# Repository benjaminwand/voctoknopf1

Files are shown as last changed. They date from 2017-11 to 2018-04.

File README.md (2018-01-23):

This is a hardware-interface vor [voctomix](https://github.com/voc/voctomix/tree/master/voctocore), developed late 2017 and tried in a few talks at 34c3.

### Key features are:

* Custom PCB
* Cherry MX switches with custom 3D-printed keycaps
* 3D-printed top and bottom enclosure parts “sandwiched” around the PCB
* Arduino Nano which sends commands to a computer via USB
* Computer relays the commands to the voctomix software via [socat](https://linux.die.net/man/1/socat)
* is supposed to learn to speak TPC on its own (was not implemented on 34c3)

This is a community project with help from many friends.

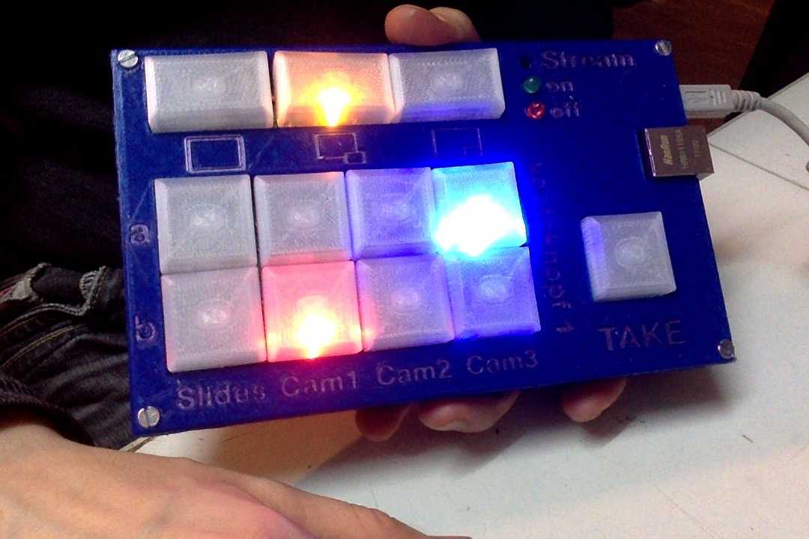
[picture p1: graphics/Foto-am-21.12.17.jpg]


The **keycaps** are [gothic.FCStd](https://github.com/benjaminwand/Cherry-MX-keycaps/tree/master/with%20LED), 20 * 33,5 mm for the composite mode buttons and 25 * 25 mm for the camera/channel buttons and the take button. Please adjust the side lengths in the spreadsheet of the file, but there are also stl files in the ‘case’ folder.

### Lessons learnt after PCB production V 1.0: 
* slightly wrong footprint for resistors, too short
* wrong footprint for cherry switches, contacts for LEDs are too far apart
* the Cherry MX I got from reichelt.de aren’t for PCB mount, be more careful when shopping
* wrong footprint for StreamOn switch, fix: bend up two diagonal contacts
* 1.5k ohm pull-up-resistors are required between A4 and 5V and A5 and 5V
* the buttons would look more evenly illuminated if the LED was behind the switches -> turn the Cherry MX around 180°

See [here](graphics/bugfixes.jpg) for a photo with hardware fixes.
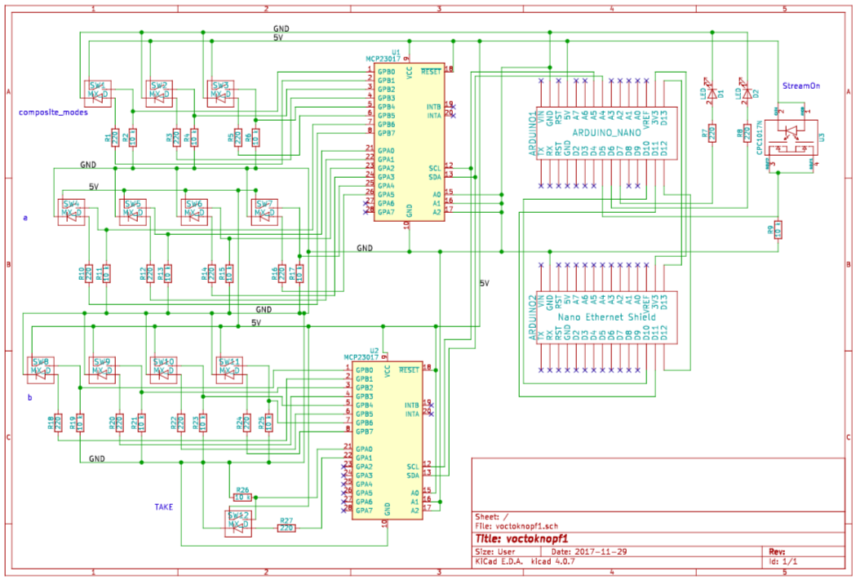
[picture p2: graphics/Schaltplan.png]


### Lessons learnt regarding the case
* I’ve actually included small changes into the file after printing, print as-is, and slice everything the way around it is supposed to end up. Yes, printing the buttons upside down would be faster but looks ugly. I found it easier to remove the support-material when the buttons were printed with raft.
* Print everything with transparent filament and then paint up the upper side of the case (except from the letters !!!) with a dark-ish pen that isn’t water-soluble. Due to the LEDs inside, the letters become illuminated.

### Shopping list
* 1 arduino nano (clone)
* 1 ethernet-shield for arduino nano
* 12 Cherry MX switches with holes for LEDs, for PCB mount. I used ‘clear’ and would go for ‘brown’ next time.
* 12 3mm LEDs, 4 red, 4 blue, 4 other color (yellow). alternatively there are probably special LEDs für Cherry MX but I didn’t have the time for searching
* 1 tact switch for StreamOn-button 
* 1 5mm LED red
* 1 5mm LED green
* 14 resistors 220
* 13 resistors 10k
* 2 resistors 1.5k
* 4 nuts and bolts M3 (best: screws with countersunk head)

### Status
One device has been built so far and has been successfully used in a few talks on the 34th Chaos Communication Congress.

### References
* [Cherry MX keycaps](https://github.com/benjaminwand/Cherry-MX-keycaps)
* [Geekend Prototype](https://github.com/benjaminwand/voctoknopf-Geekend-prototype)
* [Voctoknopf as a handheld controller](https://github.com/benjaminwand/voctoplay)

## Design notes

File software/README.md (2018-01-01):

# Software for voctoknopf1

The software is written in C using the Arduino framework.  
The source code can be found in [./voctoknopf1/](./voctoknopf1).

## Compiling and flashing

In order to compile the source code you can either use the Arduino IDE or <http://platformio.org>.  

### platformio

The following commands have to be executed in the `software/` folder.

```shell
# just compiling the code
› pio run
# compiling and uploading via USB
› pio run -t upload
```

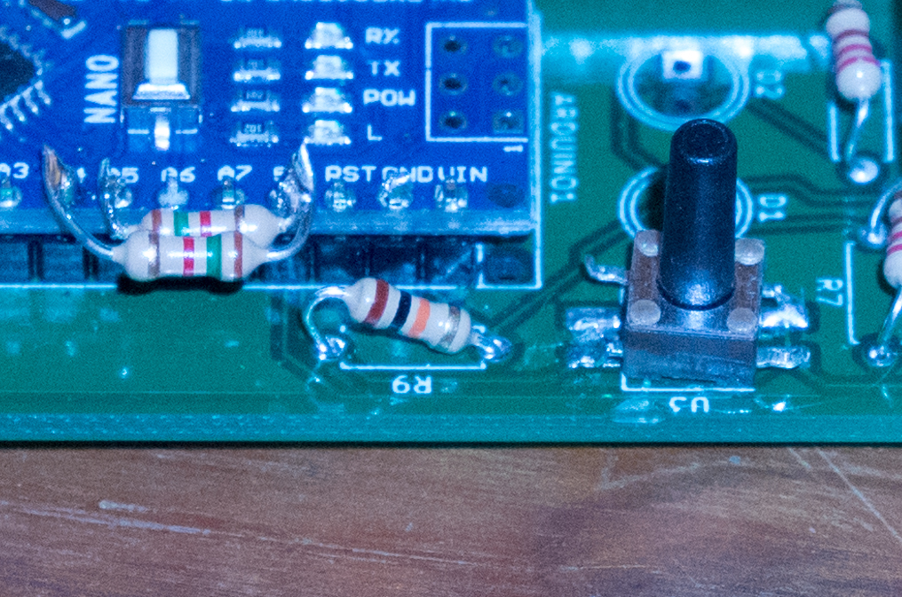
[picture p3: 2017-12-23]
graphics/bugfixes.jpg

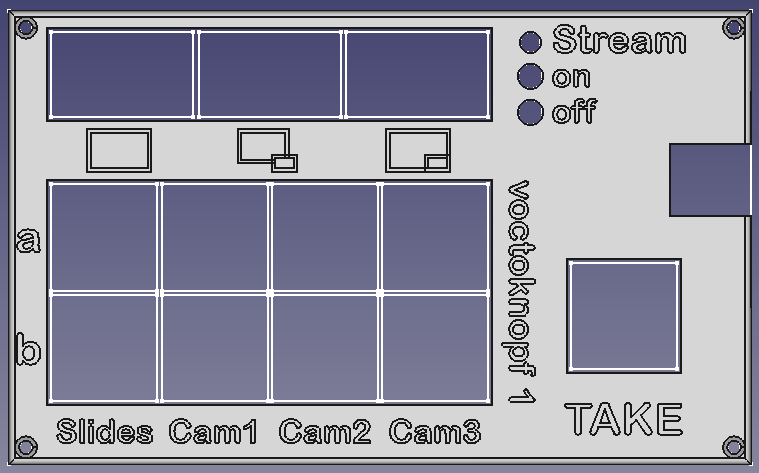
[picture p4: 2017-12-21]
graphics/mock-up-2017-12-21.png

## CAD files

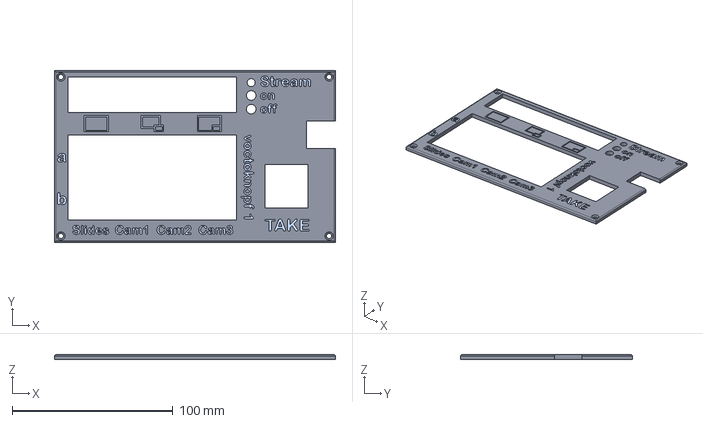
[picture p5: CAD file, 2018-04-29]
case/frontplatte multi-material (optional).FCStd
175.0 x 107.0 x 3.00 mm
Text
Platte

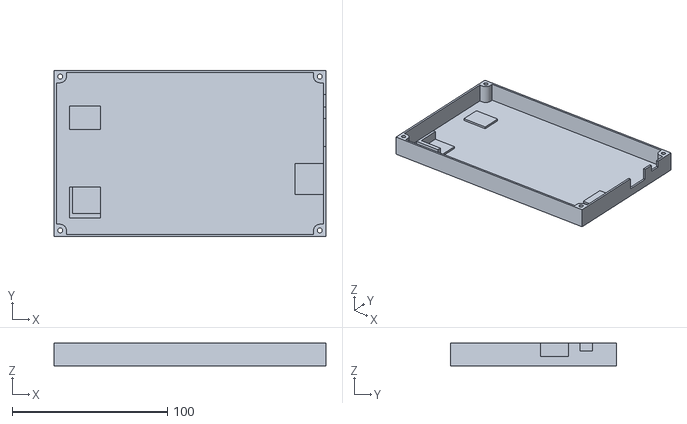
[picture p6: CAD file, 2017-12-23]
case/case unten.stl
175.0 x 107.0 x 14.6

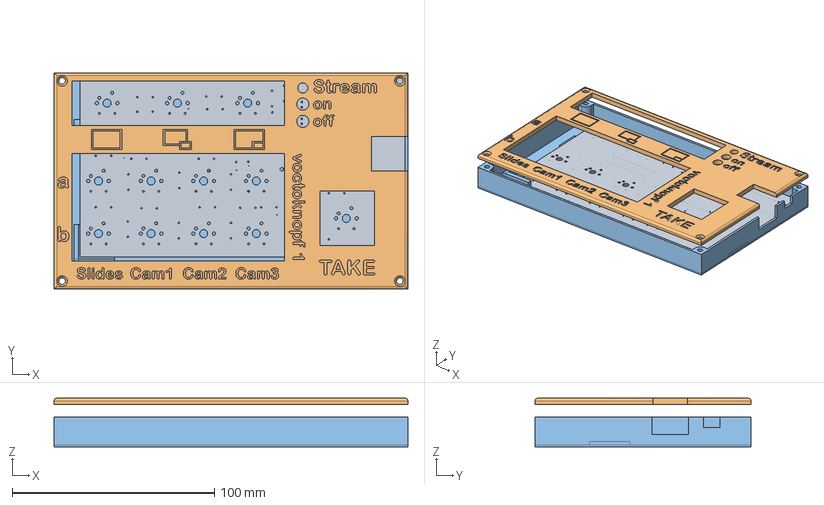
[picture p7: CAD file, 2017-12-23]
case/knopf 1.7.FCStd
175.0 x 107.0 x 24.0 mm
Cut Platine
Chamfer oben
Chamfer unten

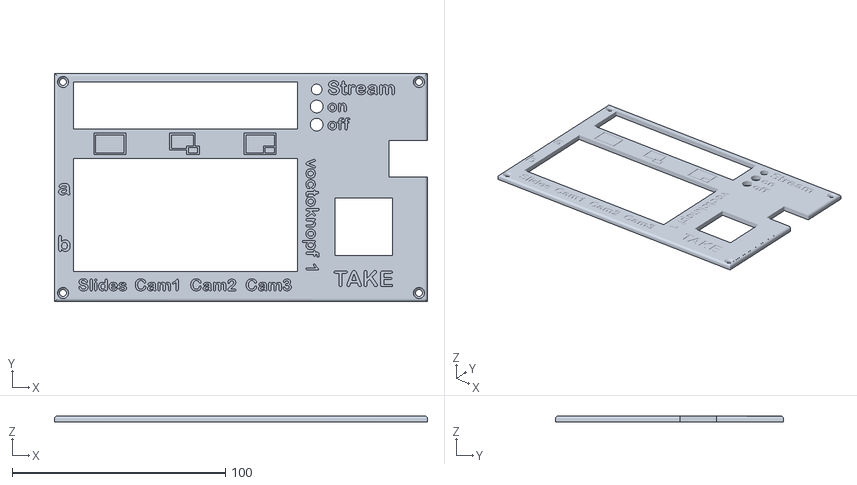
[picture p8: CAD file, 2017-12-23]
case/case oben.stl
175.0 x 107.0 x 3.00

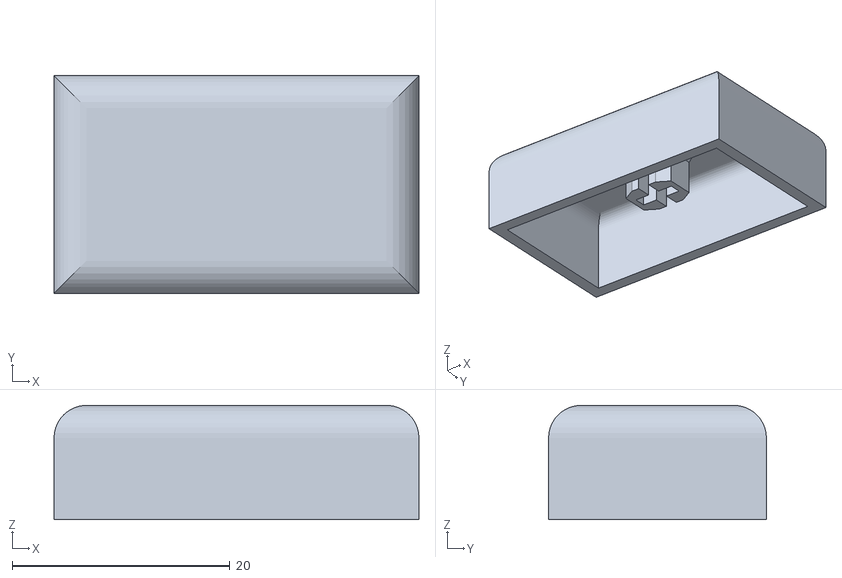
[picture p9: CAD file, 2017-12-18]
case/20x33,5.stl
33.5 x 20.0 x 10.5

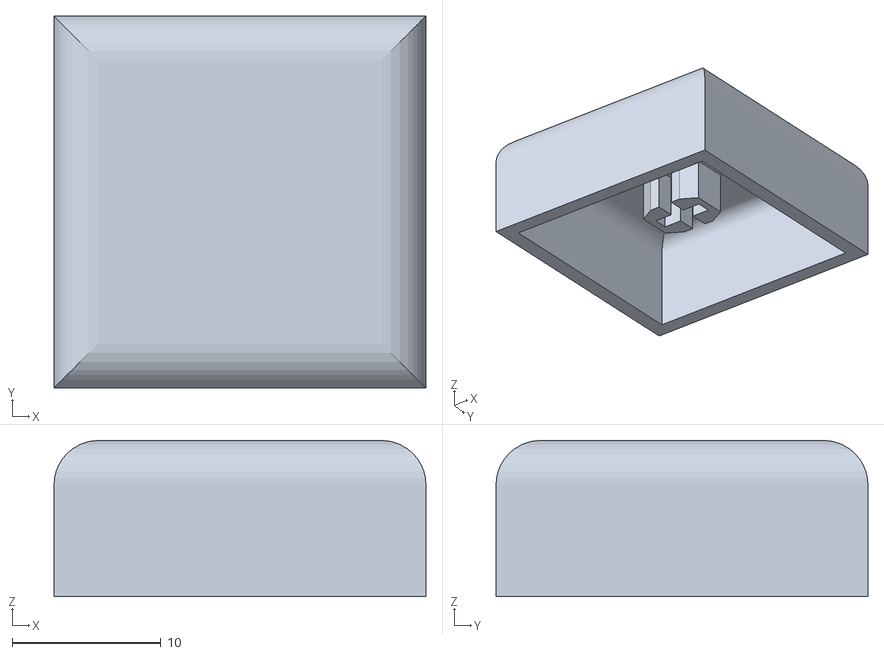
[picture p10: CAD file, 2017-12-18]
case/25x25.stl
25.0 x 25.0 x 10.5

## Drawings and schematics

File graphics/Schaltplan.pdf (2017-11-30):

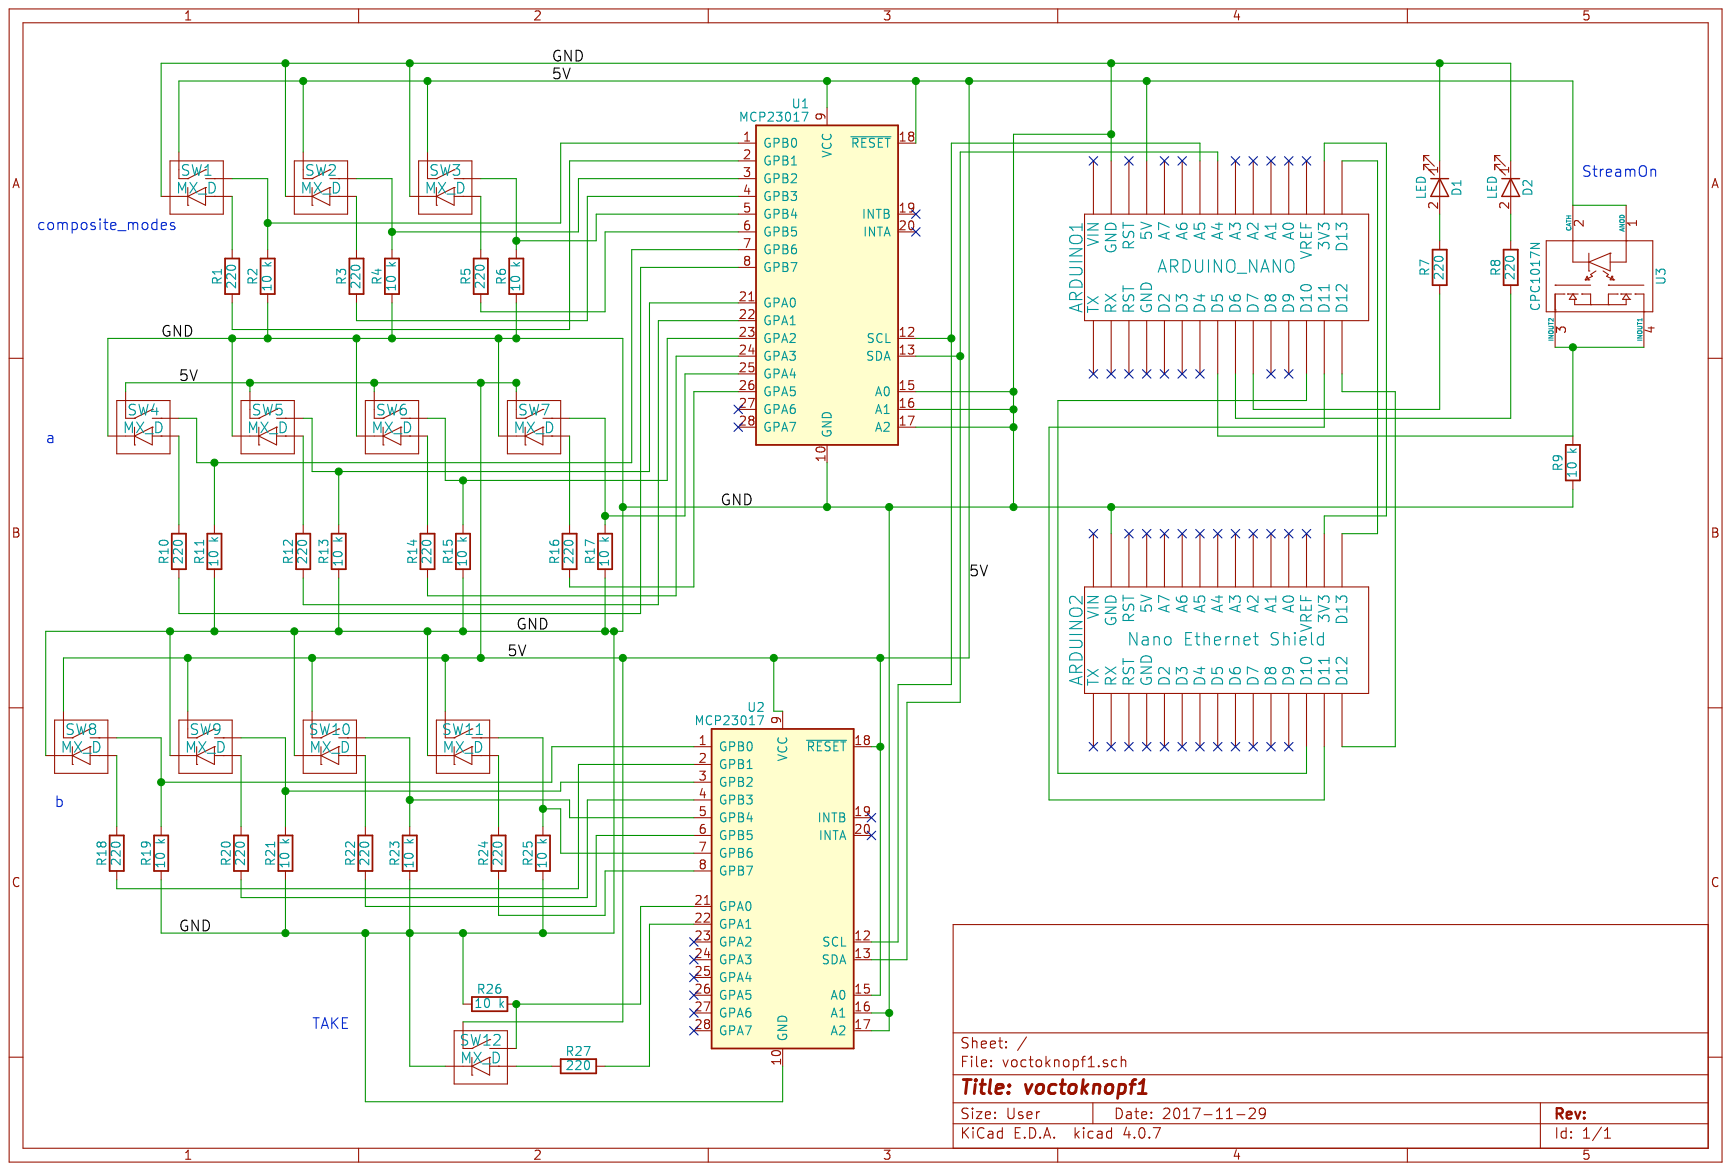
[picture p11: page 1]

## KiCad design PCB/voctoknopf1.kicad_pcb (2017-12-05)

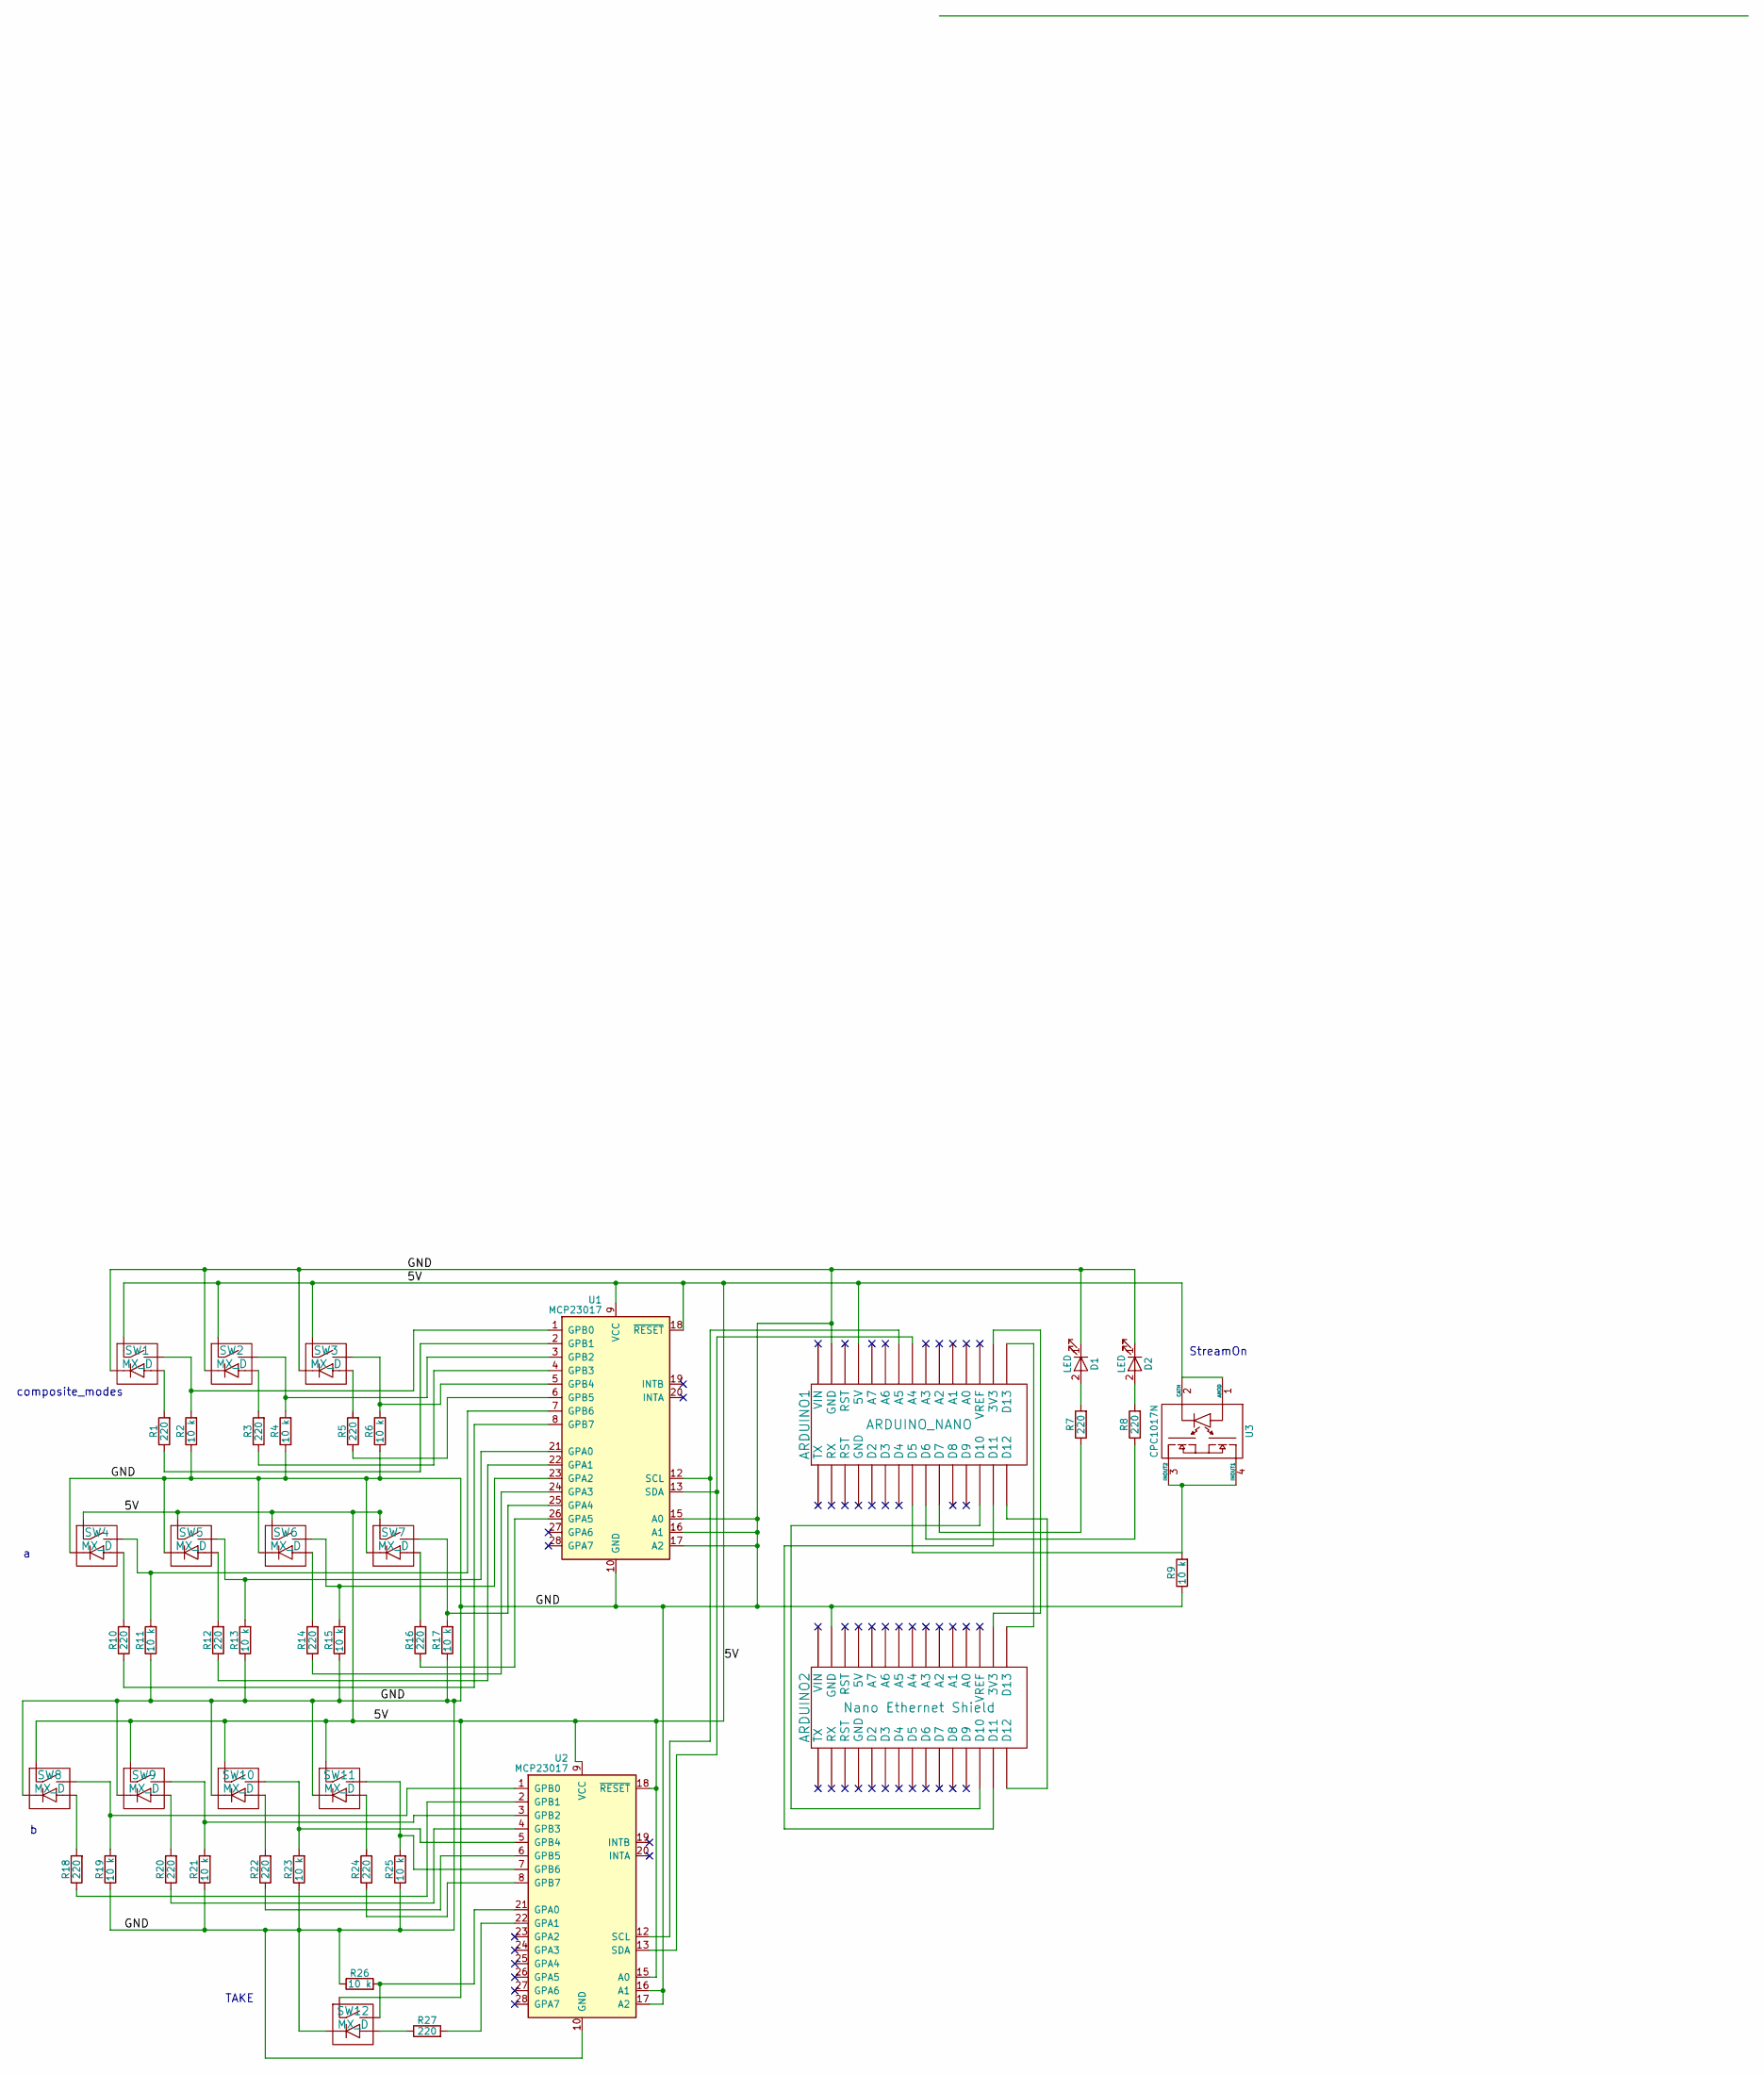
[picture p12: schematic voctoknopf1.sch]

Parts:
ARDUINO1: ARDUINO_NANO; Arduino_Nano_WithMountingHoles
ARDUINO2: Nano Ethernet Shield; Arduino_Nano_WithMountingHoles
D1, D2: LED; LED_D5.0mm
R1, R3, R5, R7, R8, R10, R12, R14, R16, R18, R20, R22, R24, R27: 220; R_Axial_DIN0207_L6.3mm_D2.5mm_P7.62mm_Horizontal
R2, R4, R6, R9, R11, R13, R15, R17, R19, R21, R23, R25, R26: 10 k; R_Axial_DIN0207_L6.3mm_D2.5mm_P7.62mm_Horizontal
SW1, SW2, SW3, SW4, SW5, SW6, SW7, SW8, SW9, SW10, SW11, SW12: MX_D; SW_PCB_4PIN
U1, U2: MCP23017; DIP-28_W7.62mm_LongPads
U3: CPC1017N; SW_DIP_x2_W8.61mm_Slide_LowProfile

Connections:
/5V: ARDUINO1.27 (5V), SW1.1 (A), SW2.1 (A), SW3.1 (A), SW4.1 (A), SW5.1 (A), SW6.1 (A), SW7.1 (A), SW8.1 (A), SW9.1 (A), SW10.1 (A), SW11.1 (A), SW12.1 (A), U1.9 (VCC), U1.18 (~RESET), U2.9 (VCC), U2.15 (A0), U2.18 (~RESET), U3.1 (ANOD), U3.2 (CATH)
/GND: ARDUINO1.29 (GND), ARDUINO2.29 (GND), D1.1 (K), D2.1 (K), R2.1, R4.1, R6.1, R9.1, R11.1, R13.1, R15.1, R17.1, R19.1, R21.1, R23.1, R25.1, R26.1, SW1.4 (D), SW2.4 (D), SW3.4 (D), SW4.4 (D), SW5.4 (D), SW6.4 (D), SW7.4 (D), SW8.4 (D), SW9.4 (D), SW10.4 (D), SW11.4 (D), SW12.4 (D), U1.10 (GND), U1.15 (A0), U1.16 (A1), U1.17 (A2), U2.10 (GND), U2.16 (A1), U2.17 (A2)
unnamed: ARDUINO1.8 (D5), R9.2, U3.3 (INOUT2), U3.4 (INOUT1)
unnamed: ARDUINO1.9 (D6), R8.1
unnamed: ARDUINO1.10 (D7), R7.1
unnamed: ARDUINO1.13 (D10), ARDUINO2.13 (D10)
unnamed: ARDUINO1.14 (D11), ARDUINO2.14 (D11)
unnamed: ARDUINO1.15 (D12), ARDUINO2.15 (D12)
unnamed: ARDUINO1.16 (D13), ARDUINO2.16 (D13)
unnamed: ARDUINO1.17 (3V3), ARDUINO2.17 (3V3)
unnamed: ARDUINO1.23 (A4), U1.13 (SDA), U2.13 (SDA)
unnamed: ARDUINO1.24 (A5), U1.12 (SCL), U2.12 (SCL)
unnamed: D1.2 (A), R7.2
unnamed: D2.2 (A), R8.2
unnamed: R1.1, U1.2 (GPB1)
unnamed: R1.2, SW1.3 (B)
unnamed: R2.2, SW1.2 (B), U1.1 (GPB0)
unnamed: R3.1, U1.4 (GPB3)
unnamed: R3.2, SW2.3 (B)
unnamed: R4.2, SW2.2 (B), U1.3 (GPB2)
unnamed: R5.1, U1.6 (GPB5)
unnamed: R5.2, SW3.3 (B)
unnamed: R6.2, SW3.2 (B), U1.5 (GPB4)
unnamed: R10.1, U1.8 (GPB7)
unnamed: R10.2, SW4.3 (B)
unnamed: R11.2, SW4.2 (B), U1.7 (GPB6)
unnamed: R12.1, U1.22 (GPA1)
unnamed: R12.2, SW5.3 (B)
unnamed: R13.2, SW5.2 (B), U1.21 (GPA0)
unnamed: R14.1, U1.24 (GPA3)
unnamed: R14.2, SW6.3 (B)
unnamed: R15.2, SW6.2 (B), U1.23 (GPA2)
unnamed: R16.1, U1.26 (GPA5)
unnamed: R16.2, SW7.3 (B)
unnamed: R17.2, SW7.2 (B), U1.25 (GPA4)
unnamed: R18.1, U2.2 (GPB1)
unnamed: R18.2, SW8.3 (B)
unnamed: R19.2, SW8.2 (B), U2.1 (GPB0)
unnamed: R20.1, U2.4 (GPB3)
unnamed: R20.2, SW9.3 (B)
unnamed: R21.2, SW9.2 (B), U2.3 (GPB2)
unnamed: R22.1, U2.6 (GPB5)
unnamed: R22.2, SW10.3 (B)
unnamed: R23.2, SW10.2 (B), U2.5 (GPB4)
unnamed: R24.1, U2.8 (GPB7)
unnamed: R24.2, SW11.3 (B)
unnamed: R25.2, SW11.2 (B), U2.7 (GPB6)
unnamed: R26.2, SW12.2 (B), U2.21 (GPA0)
unnamed: R27.1, SW12.3 (B)
unnamed: R27.2, U2.22 (GPA1)

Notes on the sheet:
StreamOn
composite_modes
TAKE

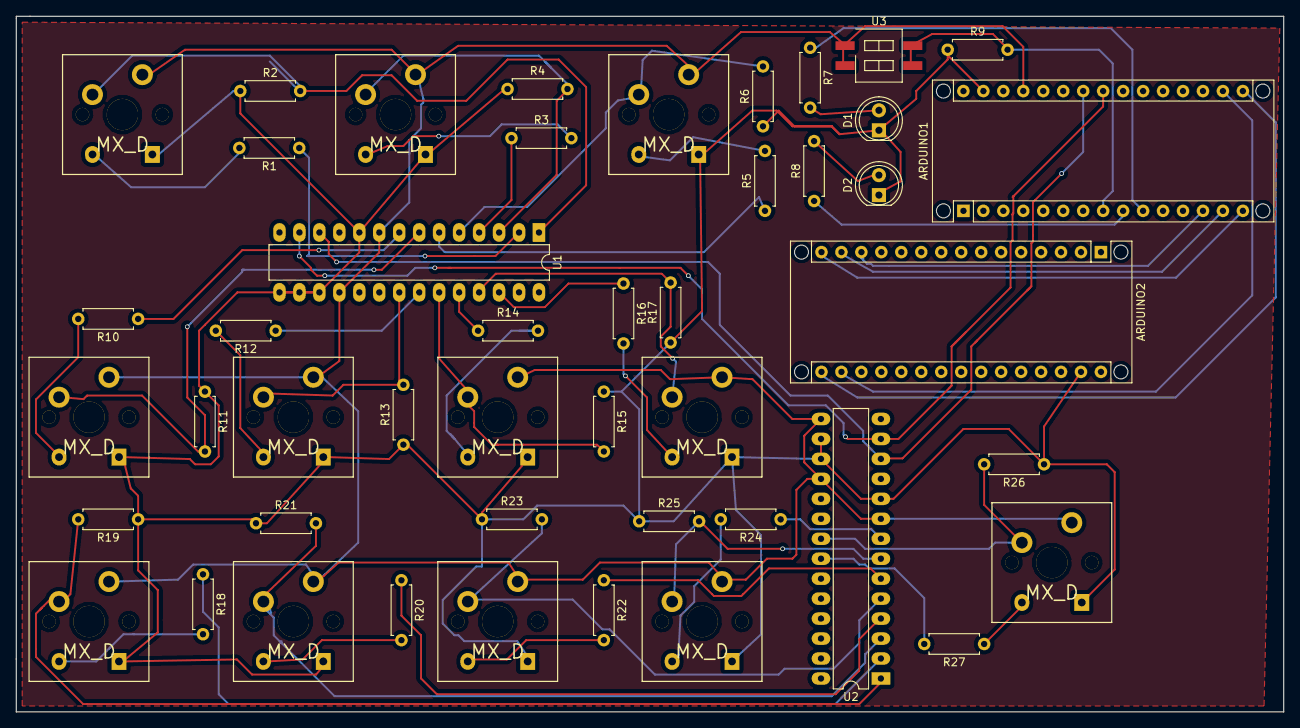
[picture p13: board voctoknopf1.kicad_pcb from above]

Board: 2 copper layers, 161.2 x 88.5 mm, 46 parts (0 on the bottom side), 50 nets.

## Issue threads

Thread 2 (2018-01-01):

Implement TCP communication to voctocore

nightvisi0n, 2018-01-01:
The Hardware hast an [enc28j60 ethernet controller](https://www.microchip.com/wwwproducts/en/en022889) on the PCB, but currently the firmware does not support it.

benjaminwand, 2018-01-01:
<off-topic> Did we get a mailing-list for free? </off-topic>

I don’t even know what exactly is the firmware in this case.

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

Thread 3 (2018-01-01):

Use interrupt functionality from I/O expander for button pressed events

nightvisi0n, 2018-01-01:
Currently we poll the I/O expander pins for state changes of the input buttons.
The I/O port expander (MCP23017) can issue interrupts on two pins whenever one of all the input pins changes (see datasheet page 24).
We should catch these interrupts in order to save cpu cycles for other things and in order to guarantee that we don't miss any button press.
However, this means we have to modify the current hardware (connect `INTA` and/or `INTB` of each I/O expander to the arduino) and the software.

benjaminwand, 2018-01-01:
Ok! What do you want to use the interrupts for? I was considering making ’take’ an interrupt but it seems fast enough.

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

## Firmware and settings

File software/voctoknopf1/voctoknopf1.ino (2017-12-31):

#include <Wire.h>
#include "Adafruit_MCP23017.h"

/*
 TODO: Ethernet
       TCP
       Kommunikation mit dem Voctocore
       StreamOn
 
  Hardware frontend for Voctomix
  https://github.com/voc/voctomix
  created 9. Nov 2017
  last changed 25. December 2017
  
  With help from 
  http://www.arduino.cc/en/Tutorial/ButtonStateChange
  and many friends
  
wenn man den voctocore fragt get_config antwortet er ngefähr sowas
"server_config {"DEFAULT": 
{}, "mix": {"videocaps": "video/x-raw,format=I420,width=960,
height=540,framerate=25/1,pixel-aspect-ratio=1/1,
interlace-mode=progressive", "audiocaps": "audio/x-raw,format=S16LE,
channels=2,layout=interleaved,rate=48000", 
"sources": "cam1,cam2,cam3,slides", "kind": "img", "imguri": 
"file:///home/sophie/Documents/rollout/background.png"}, 
"output-buffers": {"mix_out": "10000"}, "fullscreen": {}, 
"side-by-side-equal": {}, "side-by-side-preview": 
{"asize": "800x450", "apos": "12/12", "bsize": "320x180", "bpos": 
"640/360"}, "picture-in-picture": {"pipsize": "320x180", "pippos": 
"640/360"}, "previews": {"enabled": "false", "deinterlace": "false"}, 
"stream-blanker": {"enabled": "true", "sources": "pause", "volume": 
"1.0", "kind": "img", "imguri": 
"file:///home/sophie/Documents/rollout/background.png"}, 
"mirrors": {"enabled": "true"}}"
Da kann man sehen wie die chanels heißen etc.
*/

Adafruit_MCP23017 mcp1; // Create MCP 1
Adafruit_MCP23017 mcp2; // Create MCP 2

// pin mapping
const int button_fullscreen = 8;
const int led_fullscreen = 9;
const int button_side_by_side_preview = 10;
const int led_side_by_side_preview = 11;
const int button_picture_in_picture = 12;
const int led_picture_in_picture = 13;
const int button_slides_a = 14;    
const int led_slides_a = 15;    
const int button_cam1_a = 0;
const int led_cam1_a = 1;
const int button_cam2_a = 2;
const int led_cam2_a = 3;
const int button_cam3_a = 4;
const int led_cam3_a = 5;
const int button_slides_b = 8;    
const int led_slides_b = 9;    
const int button_cam1_b = 10;
const int led_cam1_b = 11;
const int button_cam2_b = 12;
const int led_cam2_b = 13;
const int button_cam3_b = 14;
const int led_cam3_b = 15;
const int button_take = 0;
const int led_take = 1;
const int button_stream = 5;
const int led_stream_red = 6;
const int led_stream_green = 7;

int buttonState = 0;                    // current state of a button
int lastButtonState_fullscreen = 0;     // previous state of each button
int lastButtonState_side_by_side_preview = 0;
int lastButtonState_picture_in_picture = 0;
int lastButtonState_slides_a = 0; 
int lastButtonState_cam1_a = 0;
int lastButtonState_cam2_a = 0;
int lastButtonState_cam3_a = 0;
int lastButtonState_slides_b = 0;
int lastButtonState_cam1_b = 0;
int lastButtonState_cam2_b = 0;
int lastButtonState_cam3_b = 0;
int lastButtonState_take = 0;
int lastButtonState_stream = 0;

String video_a = "slides";           // building blocks for take-message
String video_b = "cam1";
String composite_mode = "side_by_side_preview";

String stream_status;

void setup() {

  mcp1.begin(0);      // Start MCP 1 on Hardware address 0x20
  mcp2.begin(1);      // Start MCP 2 on Hardware address 0x21
  
  // initialize the button pins as input:
  mcp1.pinMode(button_fullscreen, INPUT);
  mcp1.pinMode(button_side_by_side_preview, INPUT);
  mcp1.pinMode(button_picture_in_picture, INPUT);
  mcp1.pinMode(button_slides_a, INPUT);
  mcp1.pinMode(button_cam1_a, INPUT);
  mcp1.pinMode(button_cam2_a, INPUT);
  mcp1.pinMode(button_cam3_a, INPUT);
  mcp2.pinMode(button_slides_b, INPUT);
  mcp2.pinMode(button_cam1_b, INPUT);
  mcp2.pinMode(button_cam2_b, INPUT);
  mcp2.pinMode(button_cam3_b, INPUT);
  mcp2.pinMode(button_take, INPUT);
  pinMode(button_stream, INPUT);
  
  // initialize the LEDs as output:
  mcp1.pinMode(led_fullscreen, OUTPUT);
  mcp1.pinMode(led_side_by_side_preview, OUTPUT);
  mcp1.pinMode(led_picture_in_picture, OUTPUT);
  mcp1.pinMode(led_slides_a, OUTPUT);
  mcp1.pinMode(led_cam1_a, OUTPUT);
  mcp1.pinMode(led_cam2_a, OUTPUT);
  mcp1.pinMode(led_cam3_a, OUTPUT);
  mcp2.pinMode(led_slides_b, OUTPUT);
  mcp2.pinMode(led_cam1_b, OUTPUT);
  mcp2.pinMode(led_cam2_b, OUTPUT);
  mcp2.pinMode(led_cam3_b, OUTPUT);
  mcp2.pinMode(led_take, OUTPUT);
  pinMode(led_stream_red, OUTPUT);
  pinMode(led_stream_green, OUTPUT);
  
  // initialize serial communication:
  Serial.begin(9600);
  Serial.println("get_stream_status");    // Stream on?
  
  // test LEDs
  mcp1.digitalWrite(led_fullscreen, HIGH);
  mcp1.digitalWrite(led_side_by_side_preview, HIGH);
  mcp1.digitalWrite(led_picture_in_picture, HIGH);
  mcp1.digitalWrite(led_slides_a, HIGH);
  mcp1.digitalWrite(led_cam1_a, HIGH);
  mcp1.digitalWrite(led_cam2_a, HIGH);
  mcp1.digitalWrite(led_cam3_a, HIGH);
  mcp2.digitalWrite(led_slides_b, HIGH);
  mcp2.digitalWrite(led_cam1_b, HIGH);
  mcp2.digitalWrite(led_cam2_b, HIGH);
  mcp2.digitalWrite(led_cam3_b, HIGH);
  mcp2.digitalWrite(led_take, HIGH);
  digitalWrite(led_stream_red, HIGH);
  digitalWrite(led_stream_green, HIGH); 
  delay(1000);
    /*
because of:
String video_a = "slides"; 
String video_b = "cam1";
String composite_mode = "side_by_side_preview";
keep some buttons illuminated:
*/
  mcp1.digitalWrite(led_fullscreen, LOW);
  mcp1.digitalWrite(led_picture_in_picture, LOW);
  mcp1.digitalWrite(led_cam1_a, LOW);
  mcp1.digitalWrite(led_cam2_a, LOW);
  mcp1.digitalWrite(led_cam3_a, LOW);
  mcp2.digitalWrite(led_slides_b, LOW);
  mcp2.digitalWrite(led_cam2_b, LOW);
  mcp2.digitalWrite(led_cam3_b, LOW);
  digitalWrite(led_stream_red, LOW);
  digitalWrite(led_stream_green, LOW); 
}


void loop() {
                                                    // OnButtonPush
  // fullscreen
  buttonState = mcp1.digitalRead(button_fullscreen);    // read the pushbutton input pin
  if (buttonState != lastButtonState_fullscreen) { // compare to lastButtonState
    if (buttonState == HIGH) {
                                               // if the current state is LOW, then 
      composite_mode = "fullscreen";               // the button just got pushed
      //Serial.println("composite_mode fullscreen selected");  // and things happen
      mcp1.digitalWrite(led_fullscreen, HIGH);
      mcp1.digitalWrite(led_side_by_side_preview, LOW);
      mcp1.digitalWrite(led_picture_in_picture, LOW);
    } 
    else {                                         // do nothing / placeholder
    }
    delay(1);                                      // delay bit to avoid bouncing 
  }
  lastButtonState_fullscreen = buttonState;        // save the current state as the last state, 
                                                   // for next time through the loop
                                                   
                                                   // end OnButtonPush 

  // side-by-side-preview
  buttonState = mcp1.digitalRead(button_side_by_side_preview);        
  if (buttonState != lastButtonState_side_by_side_preview) {     
    if (buttonState == HIGH) {                                          
      composite_mode = "side_by_side_preview";
      //Serial.println("composite_mode side_by_side_preview selected");
      mcp1.digitalWrite(led_side_by_side_preview, HIGH);
      mcp1.digitalWrite(led_fullscreen, LOW);
      mcp1.digitalWrite(led_picture_in_picture, LOW);                   
    } 
    else {
    }
    delay(1);                         
  }
  lastButtonState_side_by_side_preview = buttonState;      

  // picture_in_picture
  buttonState = mcp1.digitalRead(button_picture_in_picture);        
  if (buttonState != lastButtonState_picture_in_picture) {     
    if (buttonState == HIGH) {                                            
      composite_mode = "picture_in_picture";
      //Serial.println("composite_mode picture_in_picture selected");
      mcp1.digitalWrite(led_picture_in_picture, HIGH);
      mcp1.digitalWrite(led_side_by_side_preview, LOW);
      mcp1.digitalWrite(led_fullscreen, LOW);                  
    } 
    else {
    }
    delay(1);                         
  }
  lastButtonState_picture_in_picture = buttonState;       

  //slides_a
   buttonState = mcp1.digitalRead(button_slides_a);        
  if (buttonState != lastButtonState_slides_a) {     
    if (buttonState == HIGH) {                                            
      video_a = "slides";
      //Serial.println("slides for channel a selected");
      mcp1.digitalWrite(led_slides_a, HIGH);
      mcp1.digitalWrite(led_cam1_a, LOW);
      mcp1.digitalWrite(led_cam2_a, LOW);
      mcp1.digitalWrite(led_cam3_a, LOW);                        
    } 
    else {
    }
    delay(1);                         
  }
  lastButtonState_slides_a = buttonState;   

  //cam1_a
   buttonState = mcp1.digitalRead(button_cam1_a);        
  if (buttonState != lastButtonState_cam1_a) {     
    if (buttonState == HIGH) {                                            
      video_a = "cam1";
      //Serial.println("cam1 for channel a selected");
      mcp1.digitalWrite(led_slides_a, LOW);
      mcp1.digitalWrite(led_cam1_a, HIGH);
      mcp1.digitalWrite(led_cam2_a, LOW);
      mcp1.digitalWrite(led_cam3_a, LOW);                        
    } 
    else {
    }
    delay(1);                         
  }
  lastButtonState_cam1_a = buttonState;  
  
  //cam2_a
   buttonState = mcp1.digitalRead(button_cam2_a);        
  if (buttonState != lastButtonState_cam2_a) {     
    if (buttonState == HIGH) {                                            
      video_a = "cam2";
      //Serial.println("cam2 for channel a selected");
      mcp1.digitalWrite(led_slides_a, LOW);
      mcp1.digitalWrite(led_cam1_a, LOW);
      mcp1.digitalWrite(led_cam2_a, HIGH);
      mcp1.digitalWrite(led_cam3_a, LOW);                        
    } 
    else {
    }
    delay(1);                         
  }
  lastButtonState_cam2_a = buttonState; 

    //cam3_a
   buttonState = mcp1.digitalRead(button_cam3_a);        
  if (buttonState != lastButtonState_cam3_a) {     
    if (buttonState == HIGH) {                                            
      video_a = "cam3";
      //Serial.println("cam3 for channel a selected");
      mcp1.digitalWrite(led_slides_a, LOW);
      mcp1.digitalWrite(led_cam1_a, LOW);
      mcp1.digitalWrite(led_cam2_a, LOW);
      mcp1.digitalWrite(led_cam3_a, HIGH);                        
    } 
    else {
    }
    delay(1);                         
  }
  lastButtonState_cam3_a = buttonState;   
  
  //slides_b
   buttonState = mcp2.digitalRead(button_slides_b);        
  if (buttonState != lastButtonState_slides_b) {     
    if (buttonState == HIGH) {                                            
      video_b = "slides";
      //Serial.println("slides for channel b selected");
      mcp2.digitalWrite(led_slides_b, HIGH);
      mcp2.digitalWrite(led_cam1_b, LOW);
      mcp2.digitalWrite(led_cam2_b, LOW);
      mcp2.digitalWrite(led_cam3_b, LOW);                        
    } 
    else {
    }
    delay(1);                         
  }
  lastButtonState_slides_b = buttonState;   

  //cam1_b
   buttonState = mcp2.digitalRead(button_cam1_b);        
  if (buttonState != lastButtonState_cam1_b) {     
    if (buttonState == HIGH) {                                            
      video_b = "cam1";
      //Serial.println("cam1 for channel b selected");
      mcp2.digitalWrite(led_slides_b, LOW);
      mcp2.digitalWrite(led_cam1_b, HIGH);
      mcp2.digitalWrite(led_cam2_b, LOW);
      mcp2.digitalWrite(led_cam3_b, LOW);                        
    } 
    else {
    }
    delay(1);                         
  }
  lastButtonState_cam1_b = buttonState;  
  
  //cam2_b
   buttonState = mcp2.digitalRead(button_cam2_b);        
  if (buttonState != lastButtonState_cam2_b) {     
    if (buttonState == HIGH) {                                            
      video_b = "cam2";
      //Serial.println("cam2 for channel b selected");
      mcp2.digitalWrite(led_slides_b, LOW);
      mcp2.digitalWrite(led_cam1_b, LOW);
      mcp2.digitalWrite(led_cam2_b, HIGH);
      mcp2.digitalWrite(led_cam3_b, LOW);                        
    } 
    else {
    }
    delay(1);                         
  }
  lastButtonState_cam2_b = buttonState; 

  //cam3_b
   buttonState = mcp2.digitalRead(button_cam3_b);        
  if (buttonState != lastButtonState_cam3_b) {     
    if (buttonState == HIGH) {                                            
      video_b = "cam3";
      //Serial.println("cam3 for channel b selected");
      mcp2.digitalWrite(led_slides_b, LOW);
      mcp2.digitalWrite(led_cam1_b, LOW);
      mcp2.digitalWrite(led_cam2_b, LOW);
      mcp2.digitalWrite(led_cam3_b, HIGH);                        
    } 
    else {
    }
    delay(1);                         
  }
  lastButtonState_cam3_b = buttonState;   

  //take
   buttonState = mcp2.digitalRead(button_take);        
  if (buttonState != lastButtonState_take) {     
    if (buttonState == HIGH) {
      if(composite_mode == "fullscreen") {
         Serial.println("set_videos_and_composite " + video_a + " * " + composite_mode);                                                 
      } 
      else 
      Serial.println("set_videos_and_composite " + video_a + " " + video_b + " " + composite_mode); 
      mcp2.digitalWrite(led_take, HIGH);                        
    } 
    else {
    } 
    delay(1);                         
  }
  lastButtonState_take = buttonState;      //dann fragen ob message angekommen ist, dann LED LOW


  //stream_on 
    
  stream_status = Serial.read();
  if (stream_status == "stream_status live") {   
      digitalWrite(led_stream_red, LOW);
      digitalWrite(led_stream_green, HIGH);  
    } 
    else {
      digitalWrite(led_stream_red, HIGH);
      digitalWrite(led_stream_green, LOW);  
    }
//    
    
    buttonState = digitalRead(button_stream);      //OnButtonPush
   if (buttonState != lastButtonState_stream) {     
    if (buttonState == HIGH) {   
          if (stream_status == "> stream_status live") {       
              Serial.println("set_stream_blank pause");
              digitalWrite(led_stream_red, HIGH);
              digitalWrite(led_stream_green, LOW);              
              } 
          else {
              Serial.println("set_stream live");
              digitalWrite(led_stream_red, LOW);
              digitalWrite(led_stream_green, HIGH);
            }                     
    } 
    else {
    }
    delay(1);                         
  }
  
  lastButtonState_stream = buttonState;  
  
}

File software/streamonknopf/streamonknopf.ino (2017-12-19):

int ledPin = 6; // choose the pin for the LED
int inPin = 5;   // choose the input pin (for a pushbutton)
int val = 0;     // variable for reading the pin status

void setup() {
  pinMode(ledPin, OUTPUT);  // declare LED as output
  pinMode(inPin, INPUT);    // declare pushbutton as input
  Serial.begin(9600);
  Serial.println("Hello, world?");
}

void loop(){
  val = digitalRead(inPin);  // read input value
  if (val == HIGH) {         // check if the input is HIGH (button released)
    digitalWrite(ledPin, LOW);  // turn LED OFF
    Serial.println("pushed");
  } else {
    digitalWrite(ledPin, HIGH);  // turn LED ON
  }
}

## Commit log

2017-11-23 initial commit
    hässlich aber wahr
    [voctoknopf1.kicad_pcb, voctoknopf1.sch]
2017-11-29 29.11.
    erster Versuch mit ethernet shiled und ich habe einen arduino nano für kicad gefunden
    [voctoknopf1.sch]
2017-11-29 case 3d file, more pcb work
    [_saved_voctoknopf1.sch, knopf 1.4.FCStd, voctoknopf1.sch]
2017-11-29 pcb weiter machen
    [_saved_voctoknopf1.sch, voctoknopf1.kicad_pcb, voctoknopf1.sch]
2017-11-29 more pcb foo
    [voctoknopf1.sch]
2017-11-29 more pcb
    [voctoknopf1.sch]
2017-11-29 PCB und Grafiken
    [voctoknopf1.sch]
2017-11-30 scematic + netlist
    [voctoknopf1.kicad_pcb, voctoknopf1.sch]
2017-11-30 sorting components on pcb
    [voctoknopf1.kicad_pcb]
2017-11-30 pcb work
    [voctoknopf1.kicad_pcb]
2017-11-30 pbc work
    [voctoknopf1.kicad_pcb]
2017-11-30 last saved November 2017
    [voctoknopf1.kicad_pcb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]
2017-12-02 ethernet shild the right way around
    [voctoknopf1.kicad_pcb]
2017-12-02 irgendwas mit footprints, und gerberfiles
    [voctoknopf1.kicad_pcb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]
2017-12-03 dpi 89
    [voctoknopf1.kicad_pcb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]
2017-12-03 ordentliche Proportionen
    [voctoknopf1.kicad_pcb]
2017-12-03 pbc done
    [voctoknopf1.kicad_pcb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]
2017-12-03 pcb bug free (so it says), and new freecad file
    [knopf 1.4.FCStd, knopf 1.6.FCStd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]
2017-12-04 aufräumen, gerber files for manufacturer
    [voctoknopf1-B.Adhes.gbr, voctoknopf1-B.CrtYd.gbr, voctoknopf1-B.Cu.gbr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]
2017-12-04 minor edit
    [knopf 1.6.FCStd]
2017-12-05 removed superfluous via
    [voctoknopf1.kicad_pcb]
2017-12-14 readme-update, new software file (wire)
2017-12-18 case design
    [knopf 1.6.FCStd]
2017-12-19 more lessons learnt + case work
    [case oben.stl, knopf 1.6.FCStd]
2017-12-19 case work
    [case unten2.stl, knopf 1.6.FCStd, knopf 1.7.FCStd]
2017-12-25 LED test when booting
2017-12-30 wie heißt das Device auf meinem Rechner?
2018-01-07 lessons learnt - case
2018-04-29 multi material front (optional)
    [frontplatte multi-material (optional).FCStd]
